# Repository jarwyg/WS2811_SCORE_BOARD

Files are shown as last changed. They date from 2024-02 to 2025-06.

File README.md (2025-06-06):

# WS2811_SCORE_BOARD

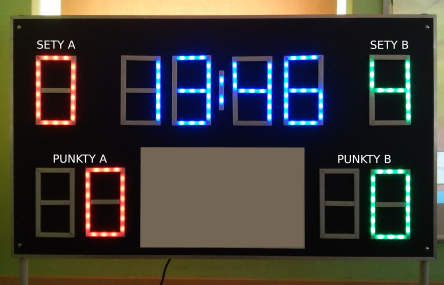
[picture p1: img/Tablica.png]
Tablica


W 2017 wraz z znajomym z roku stworzyliśmy tablicę wyników zbudowaną z wykorzystaniem pasków LED WS2811.

W 2024 projekt został ulepszony pod względem hardware oraz firmware. Aktualnie jest opublikownay jako open-source (MIT License) 

# Firmware

Firmware jest napisany w jęzku c.
Projekt był stworzony w Eclipse z AVR plugin (kompilator avr-gcc). Katalog Release zawiera pliki makefile więc można projekt skompliować z poziomu terminala.
Gotowe pliki binarne można znaleźć poniżej

[Firmware Release v1.2](https://github.com/jarwyg/WS2811_SCORE_BOARD/releases/tag/v1.2)

# Receiver

Odbiornik działa na mikrokontrolerze Atmega88/168/328 (16MHz - zawnętrzny oscylator).
Czas jest brany z RTC PCF8563.
Płytka powinna mieć wgrany bootloader z arduino UNO. Dzięki temu po podłączeniu przejściówki USB-UART łatwiej będzie wgrać aktualizację/zobaczyć debug podczas pracy układu. Tablica prawdopodobnie będzie w niedostępnym miejscu więc zalecam zostawienie długiego przewodu USB/RS232 

PCB
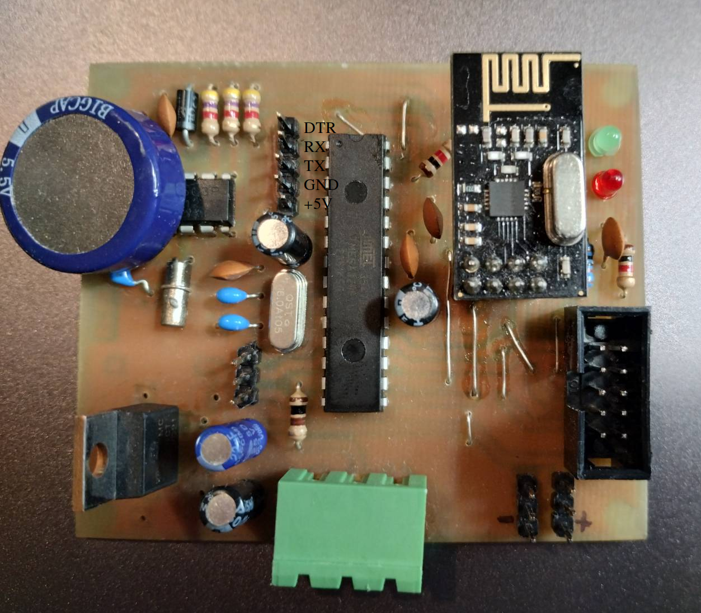
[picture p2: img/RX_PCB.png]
PCB_RX


# Transmitter

Pilot działa na mikrokontrolerze Atmega88/168/328 (8MHz - wewnętrzny oscylator)
Domyślnie jest w trybie uśpienia i pownien pobierać mniej niż 70uA.
Komunikacja z odbiornikiem odbywa się tylko w jedną stronę.

Opis przycisków
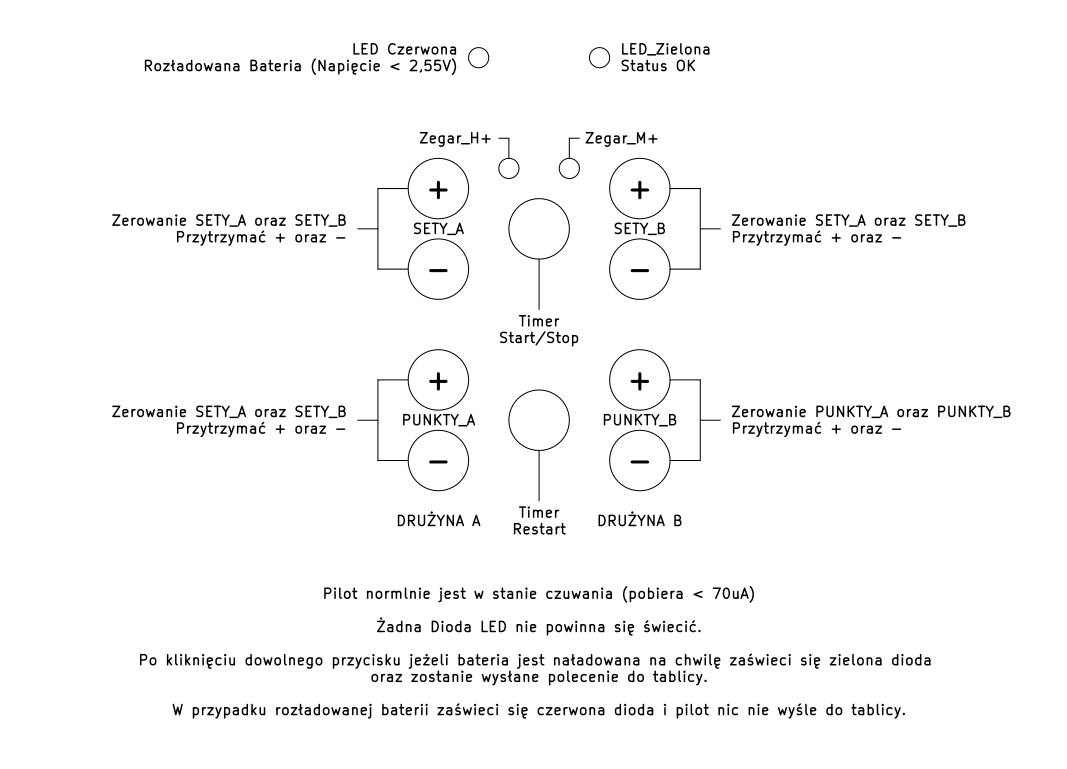
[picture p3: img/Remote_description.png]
Opis przycisków


PCB
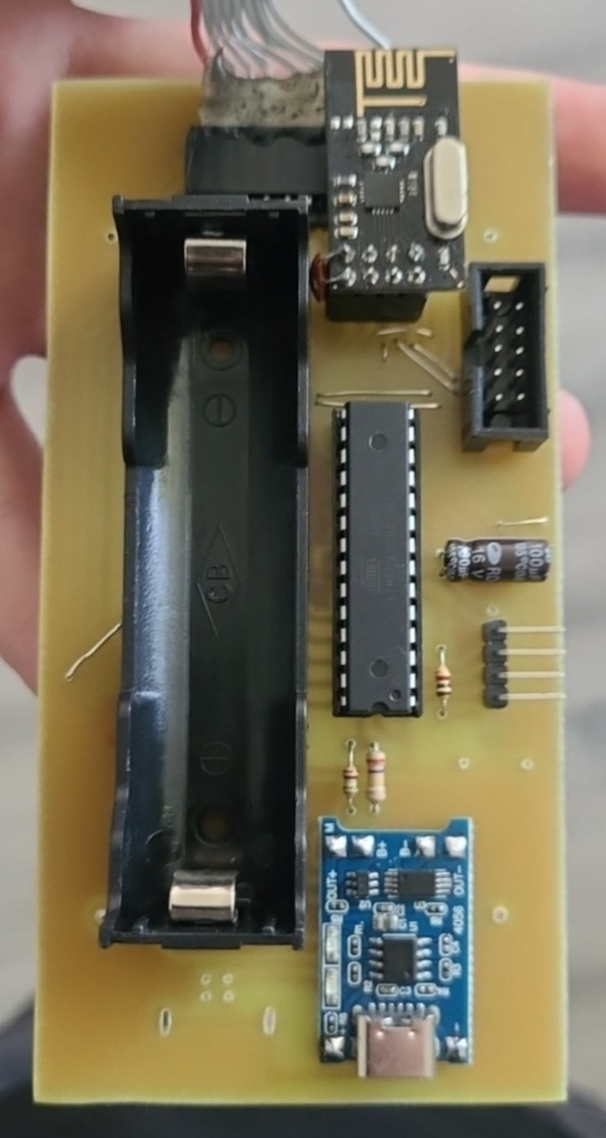
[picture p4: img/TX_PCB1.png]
PCB_TX1


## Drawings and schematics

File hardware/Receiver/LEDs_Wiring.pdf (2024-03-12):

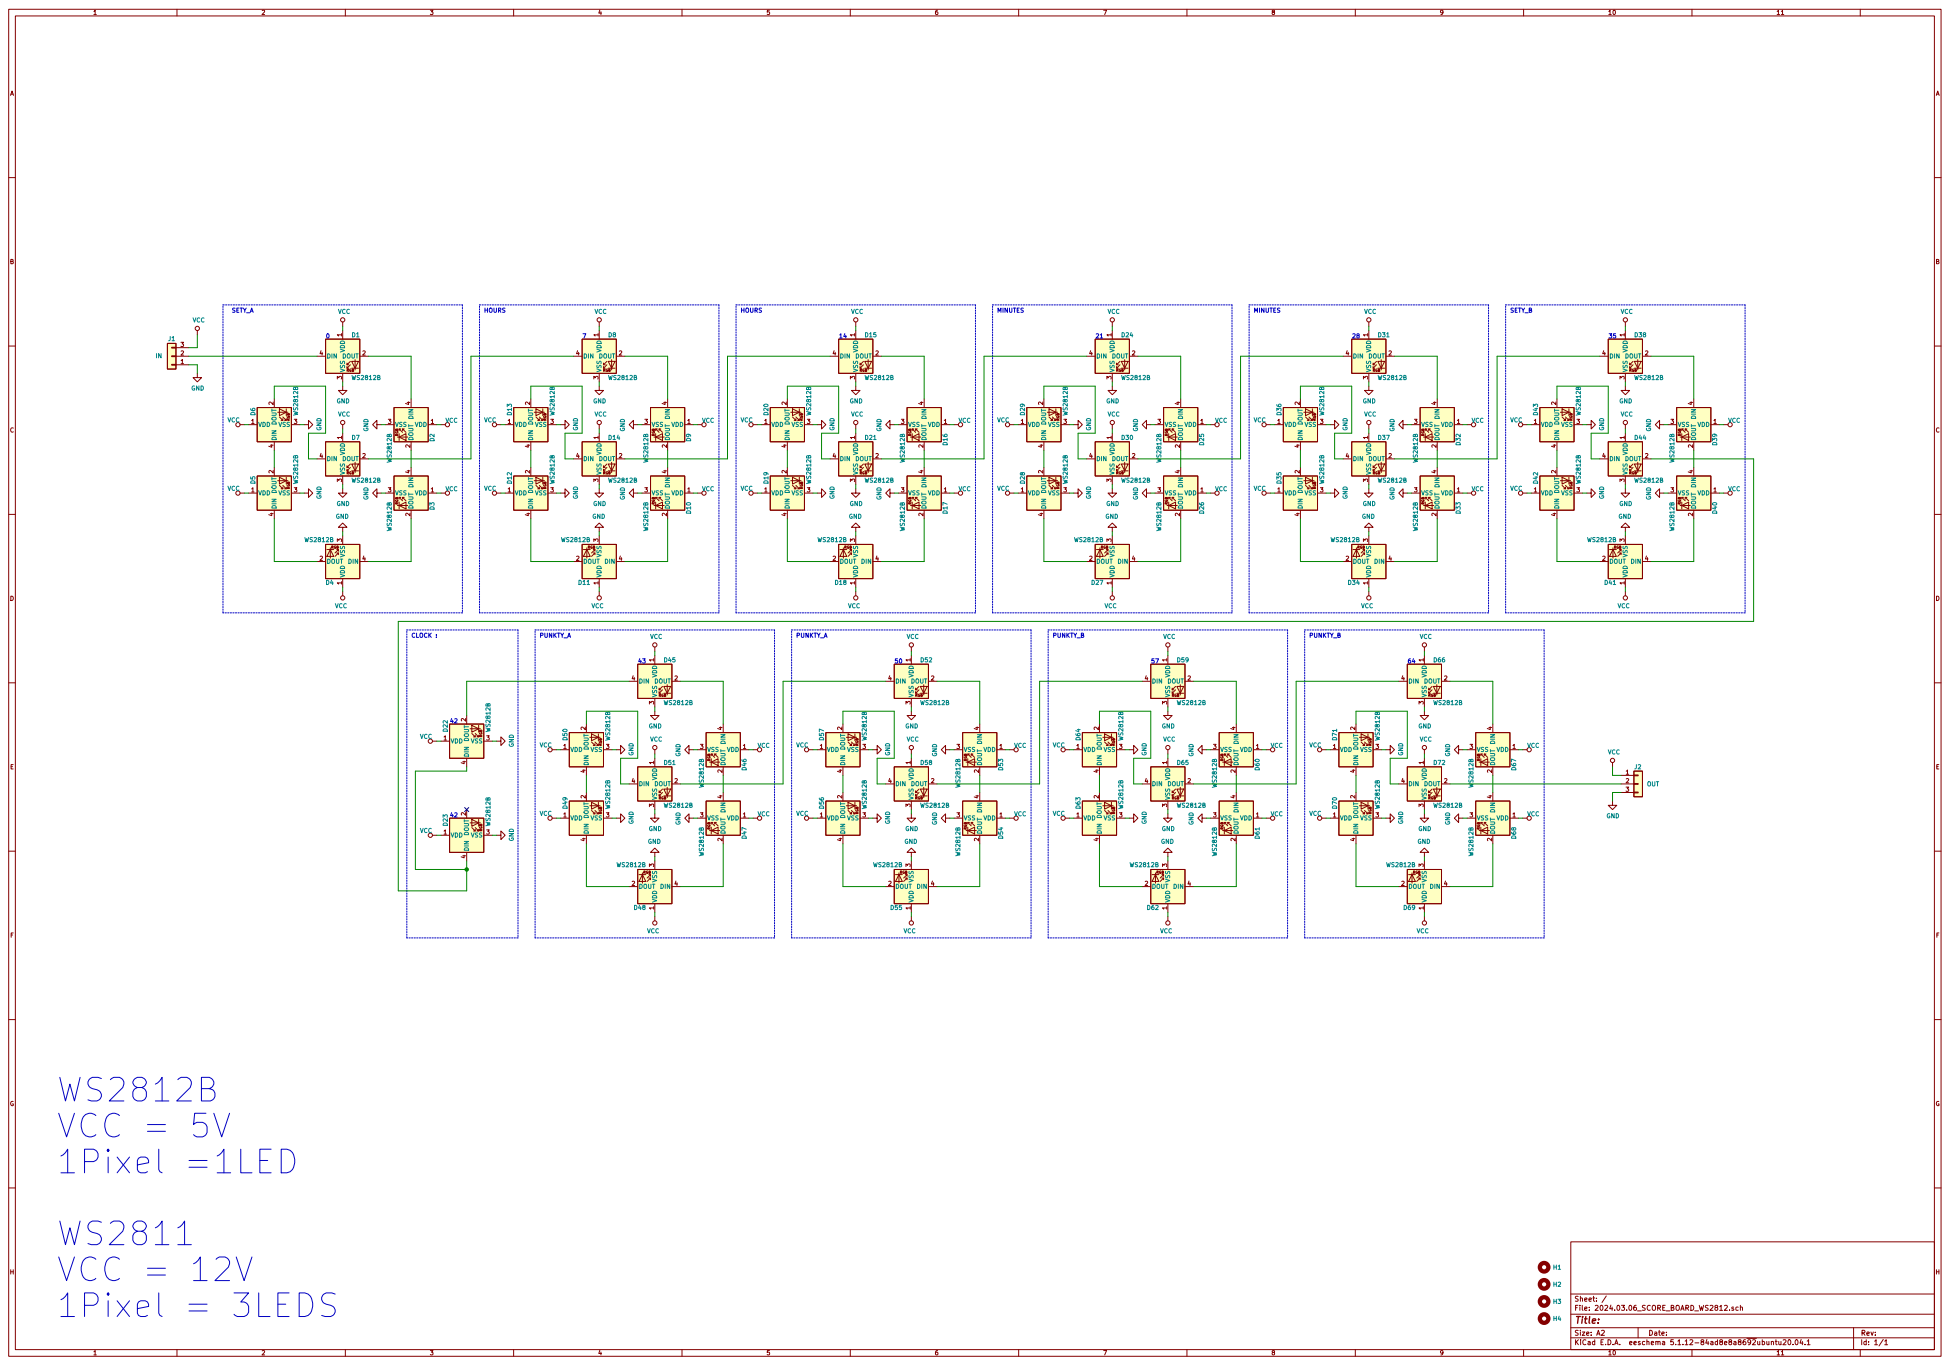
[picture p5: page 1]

3 DIN 4 D1WS2812B GND GND GND GND GND GND GND GND GND GND GND GND GND GND GND
RGB VDD

3 DIN 4 D15 WS2812B RGB VDD 1 DOUT

3 DIN 4 D30 WS2812B GND GND GND GNDRGB VDD
VCC

4 D28 WS2812B GND RGB VDD 1 DOUT

3 DIN 4 D11 WS2812B RGB VDD 1 DOUT

3 DIN 4 D18 WS2812B RGB VDD 1 DOUT

3 DIN 4 D27 WS2812B RGB VDD 1 DOUT

3 DIN 4 D52 WS2812B RGB VDD 1 DOUT

4 D53 WS2812B GND RGB VDD 1 DOUT

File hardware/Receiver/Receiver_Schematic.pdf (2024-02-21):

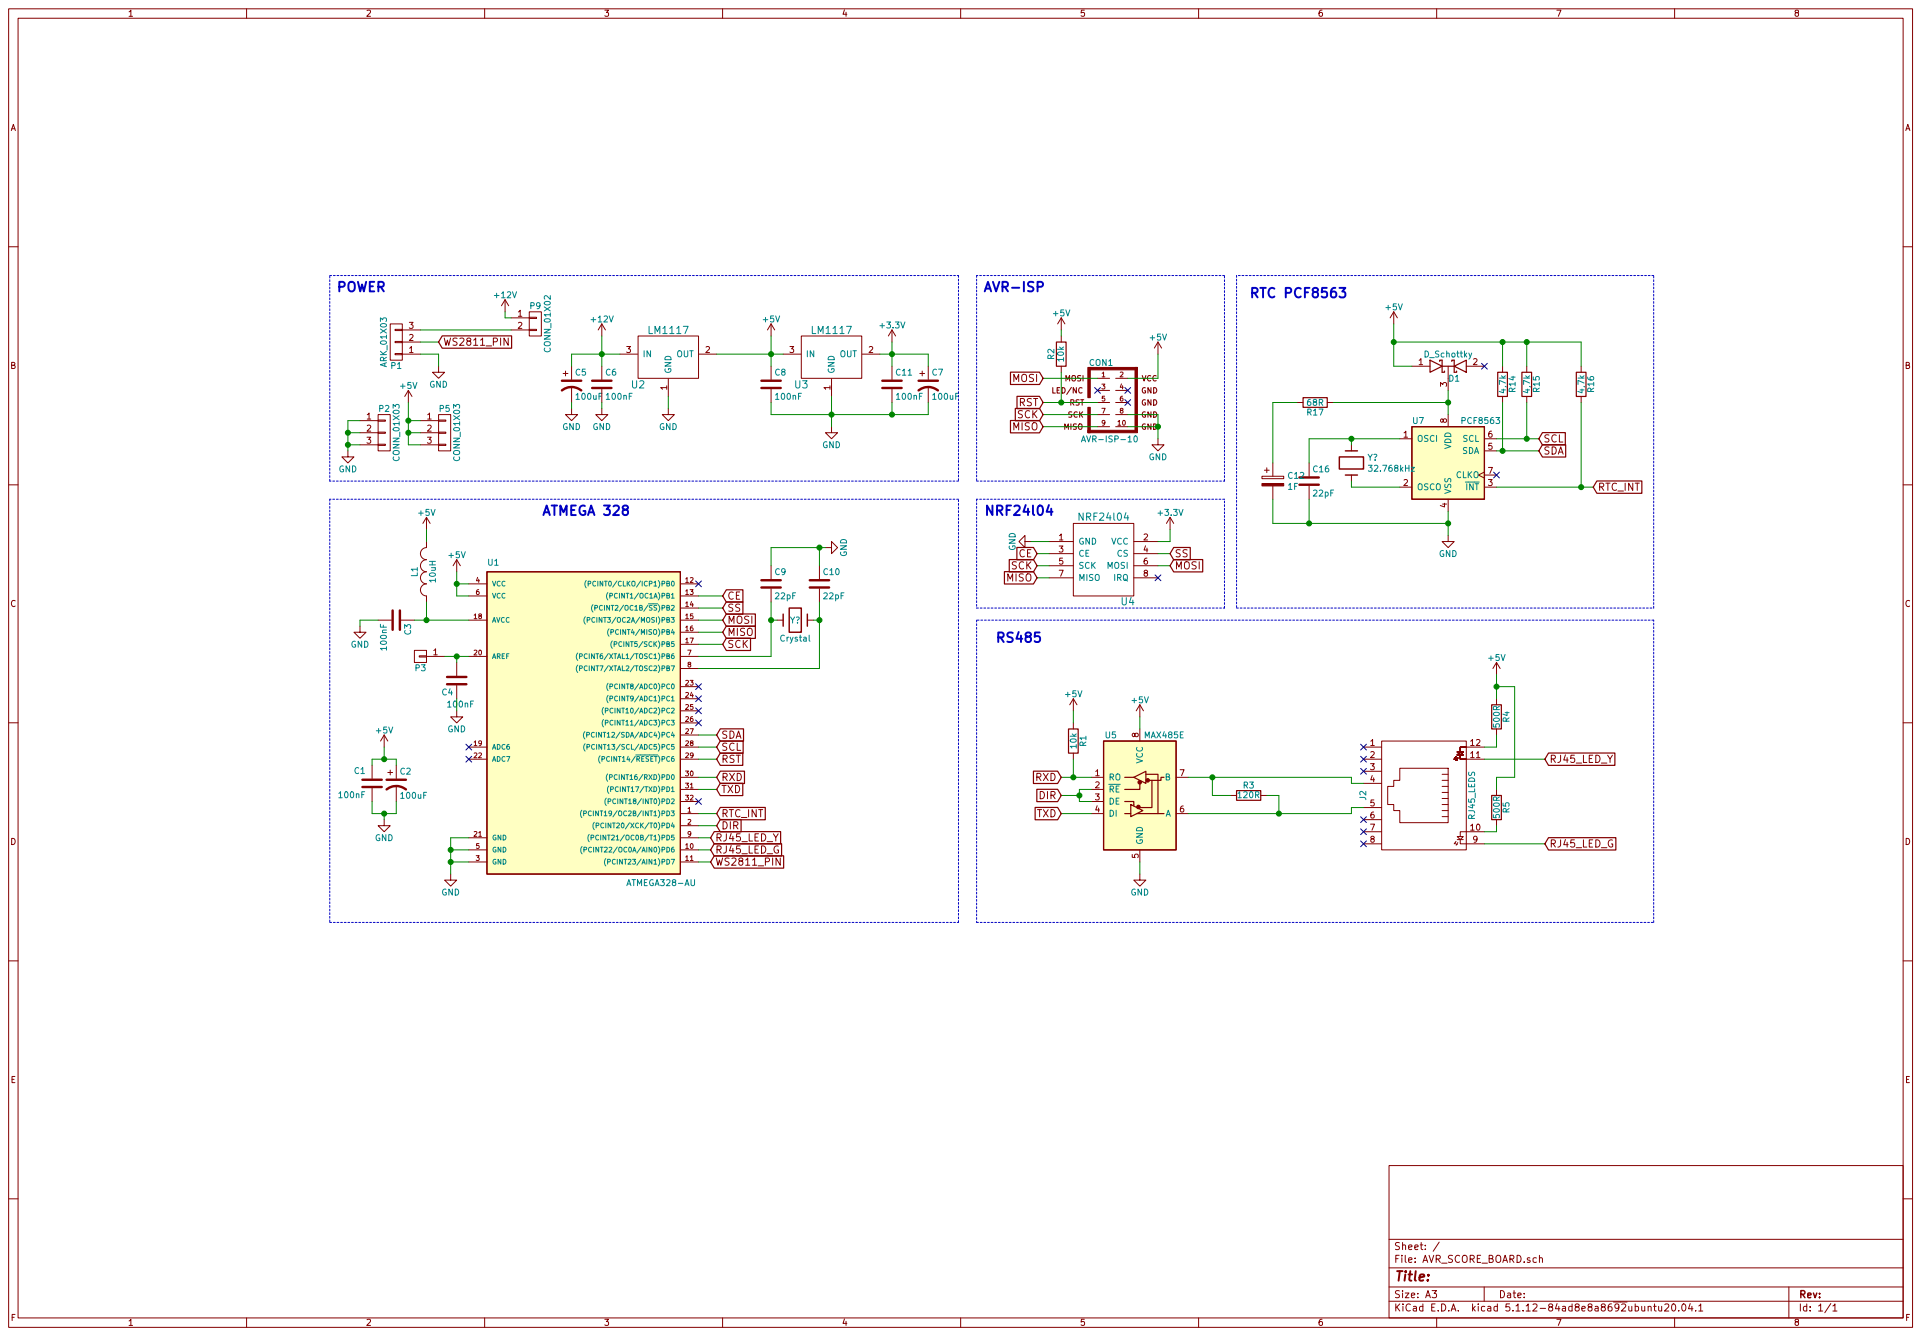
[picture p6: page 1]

9 CON1 AVR-ISP-10
VCC GND GND GND

4 SDA 5 SCL 6 CLKO 7 VDD

File: AVR_SCORE_BOARD.sch Sheet: / GND

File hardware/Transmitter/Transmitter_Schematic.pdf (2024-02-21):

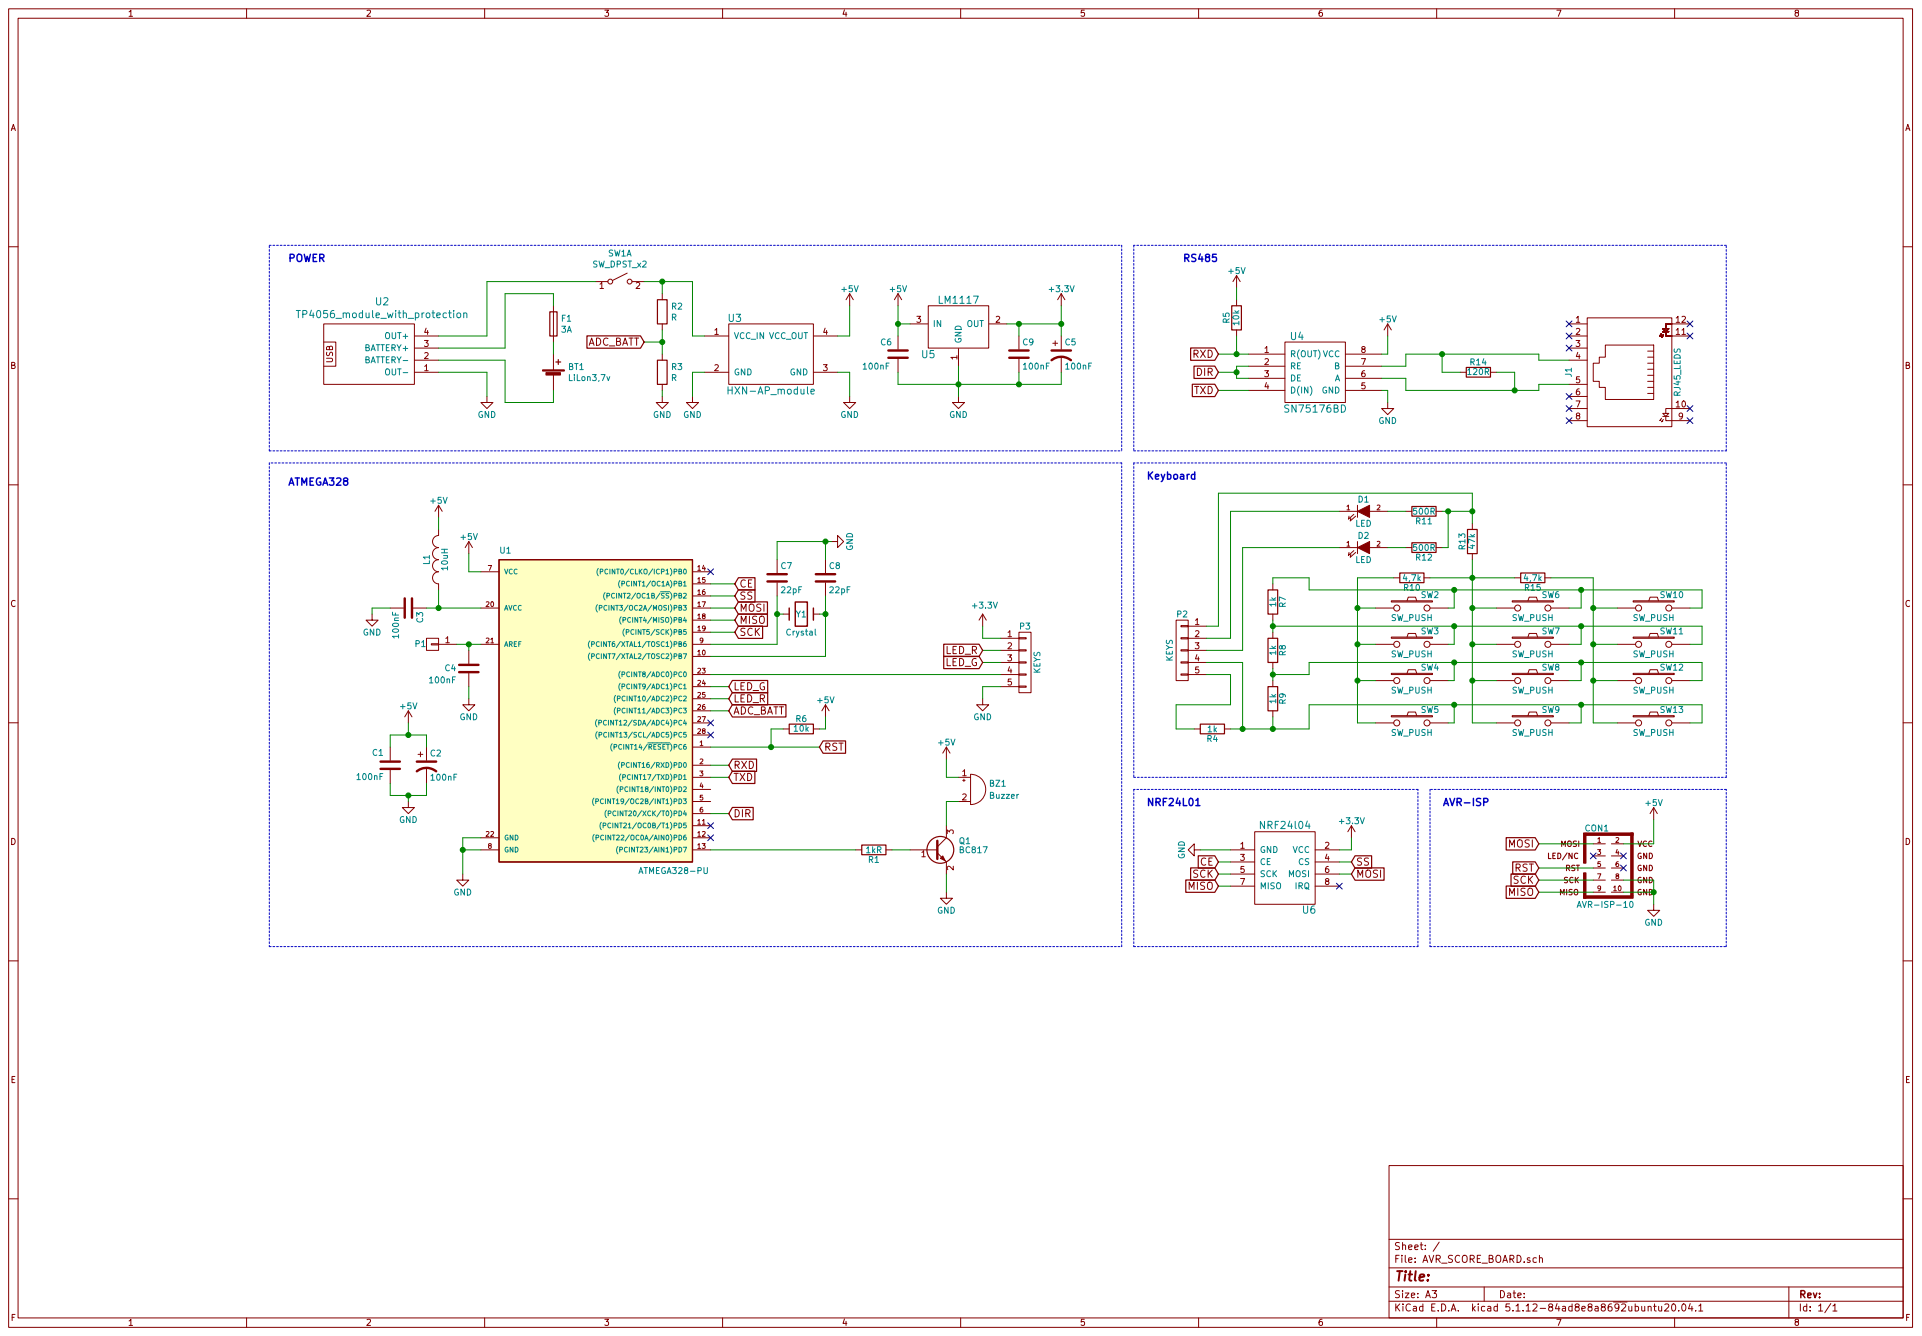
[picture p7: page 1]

VCC GND GND GND

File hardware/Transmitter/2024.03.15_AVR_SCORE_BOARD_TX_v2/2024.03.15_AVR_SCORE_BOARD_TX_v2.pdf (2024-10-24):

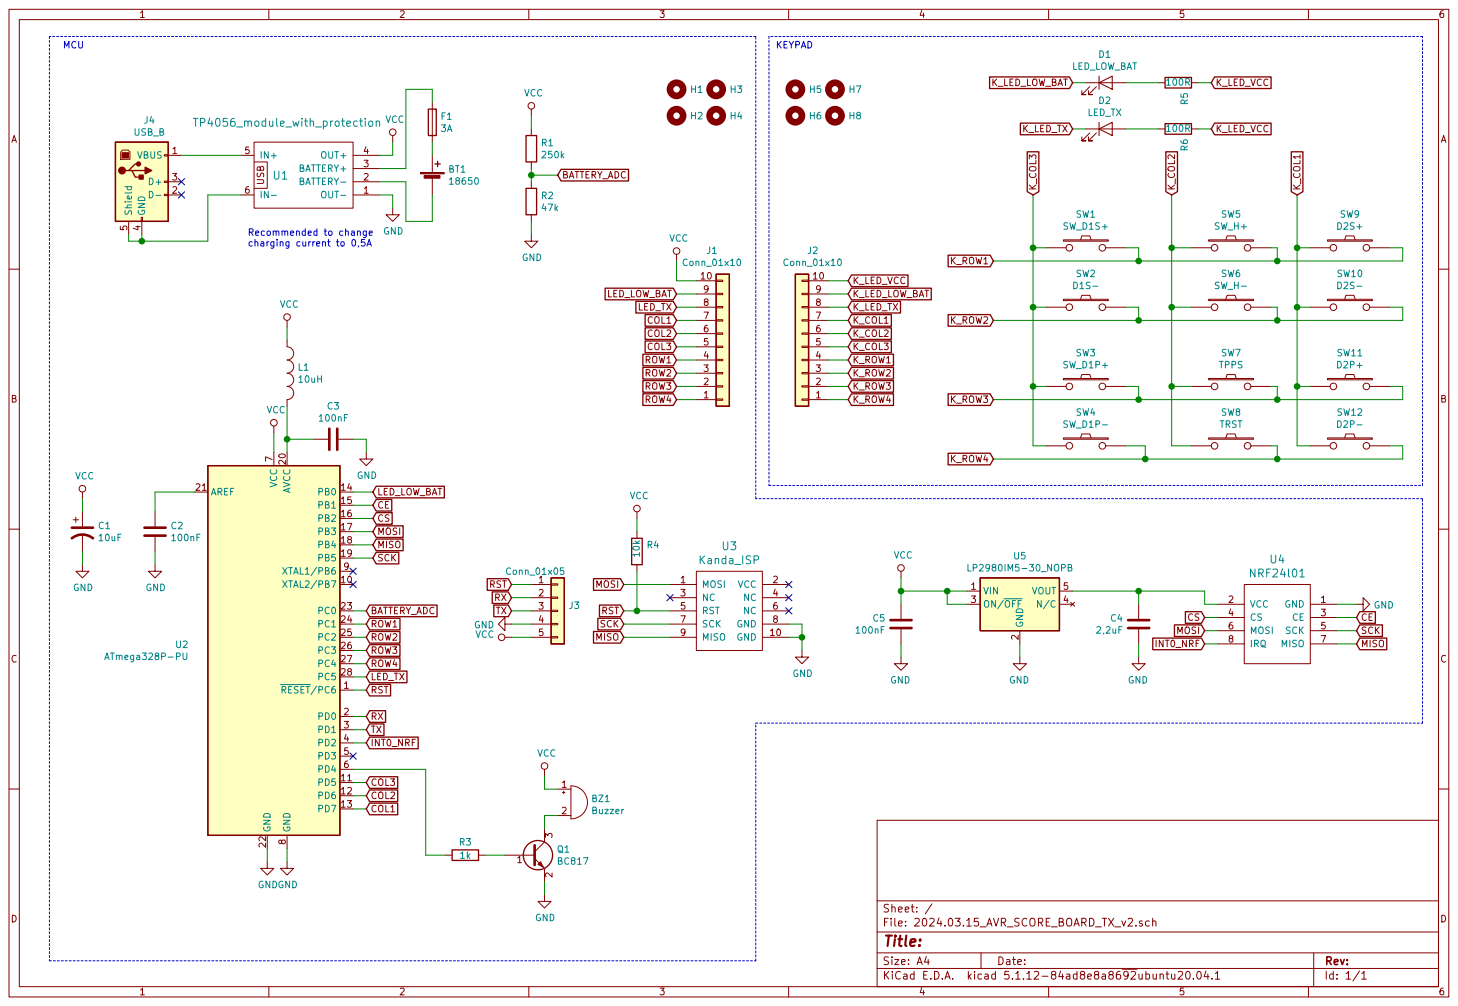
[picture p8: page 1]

8 XTAL1/PB6 9 U2 ATmega328P-PU MOSI 1 GND 10 VCC 2 NC 3 NC 4 RST 5 NC 6 SCK 7 GND 8 MISO 9 U3 Kanda_ISP

INT0_NRF RST MOSI SCK MISO

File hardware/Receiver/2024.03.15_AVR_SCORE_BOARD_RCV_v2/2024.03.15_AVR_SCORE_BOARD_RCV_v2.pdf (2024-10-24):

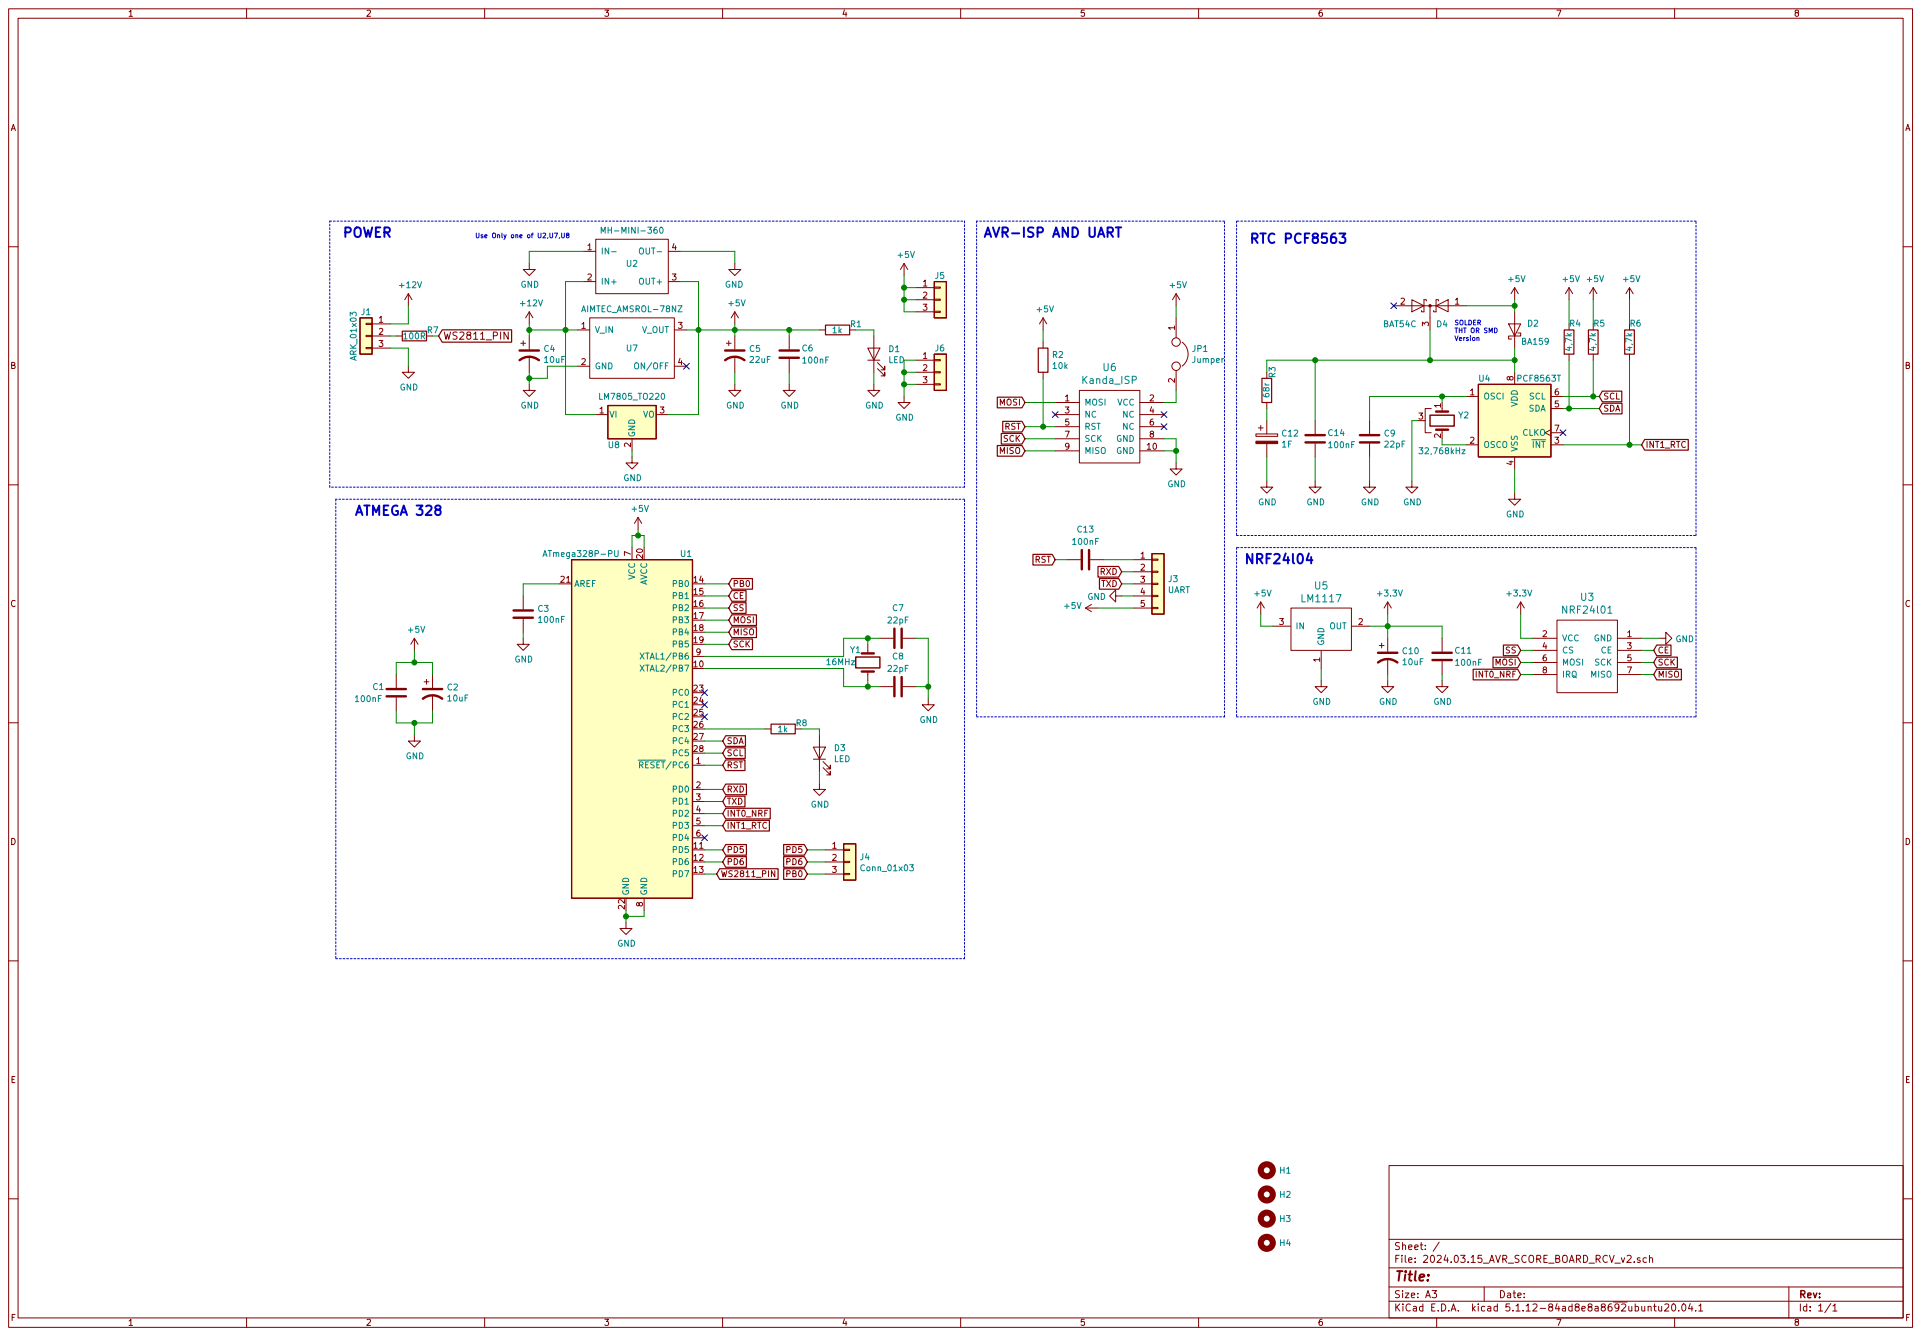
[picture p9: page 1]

4 SDA 5 SCL 6 CLKO 7 VDD

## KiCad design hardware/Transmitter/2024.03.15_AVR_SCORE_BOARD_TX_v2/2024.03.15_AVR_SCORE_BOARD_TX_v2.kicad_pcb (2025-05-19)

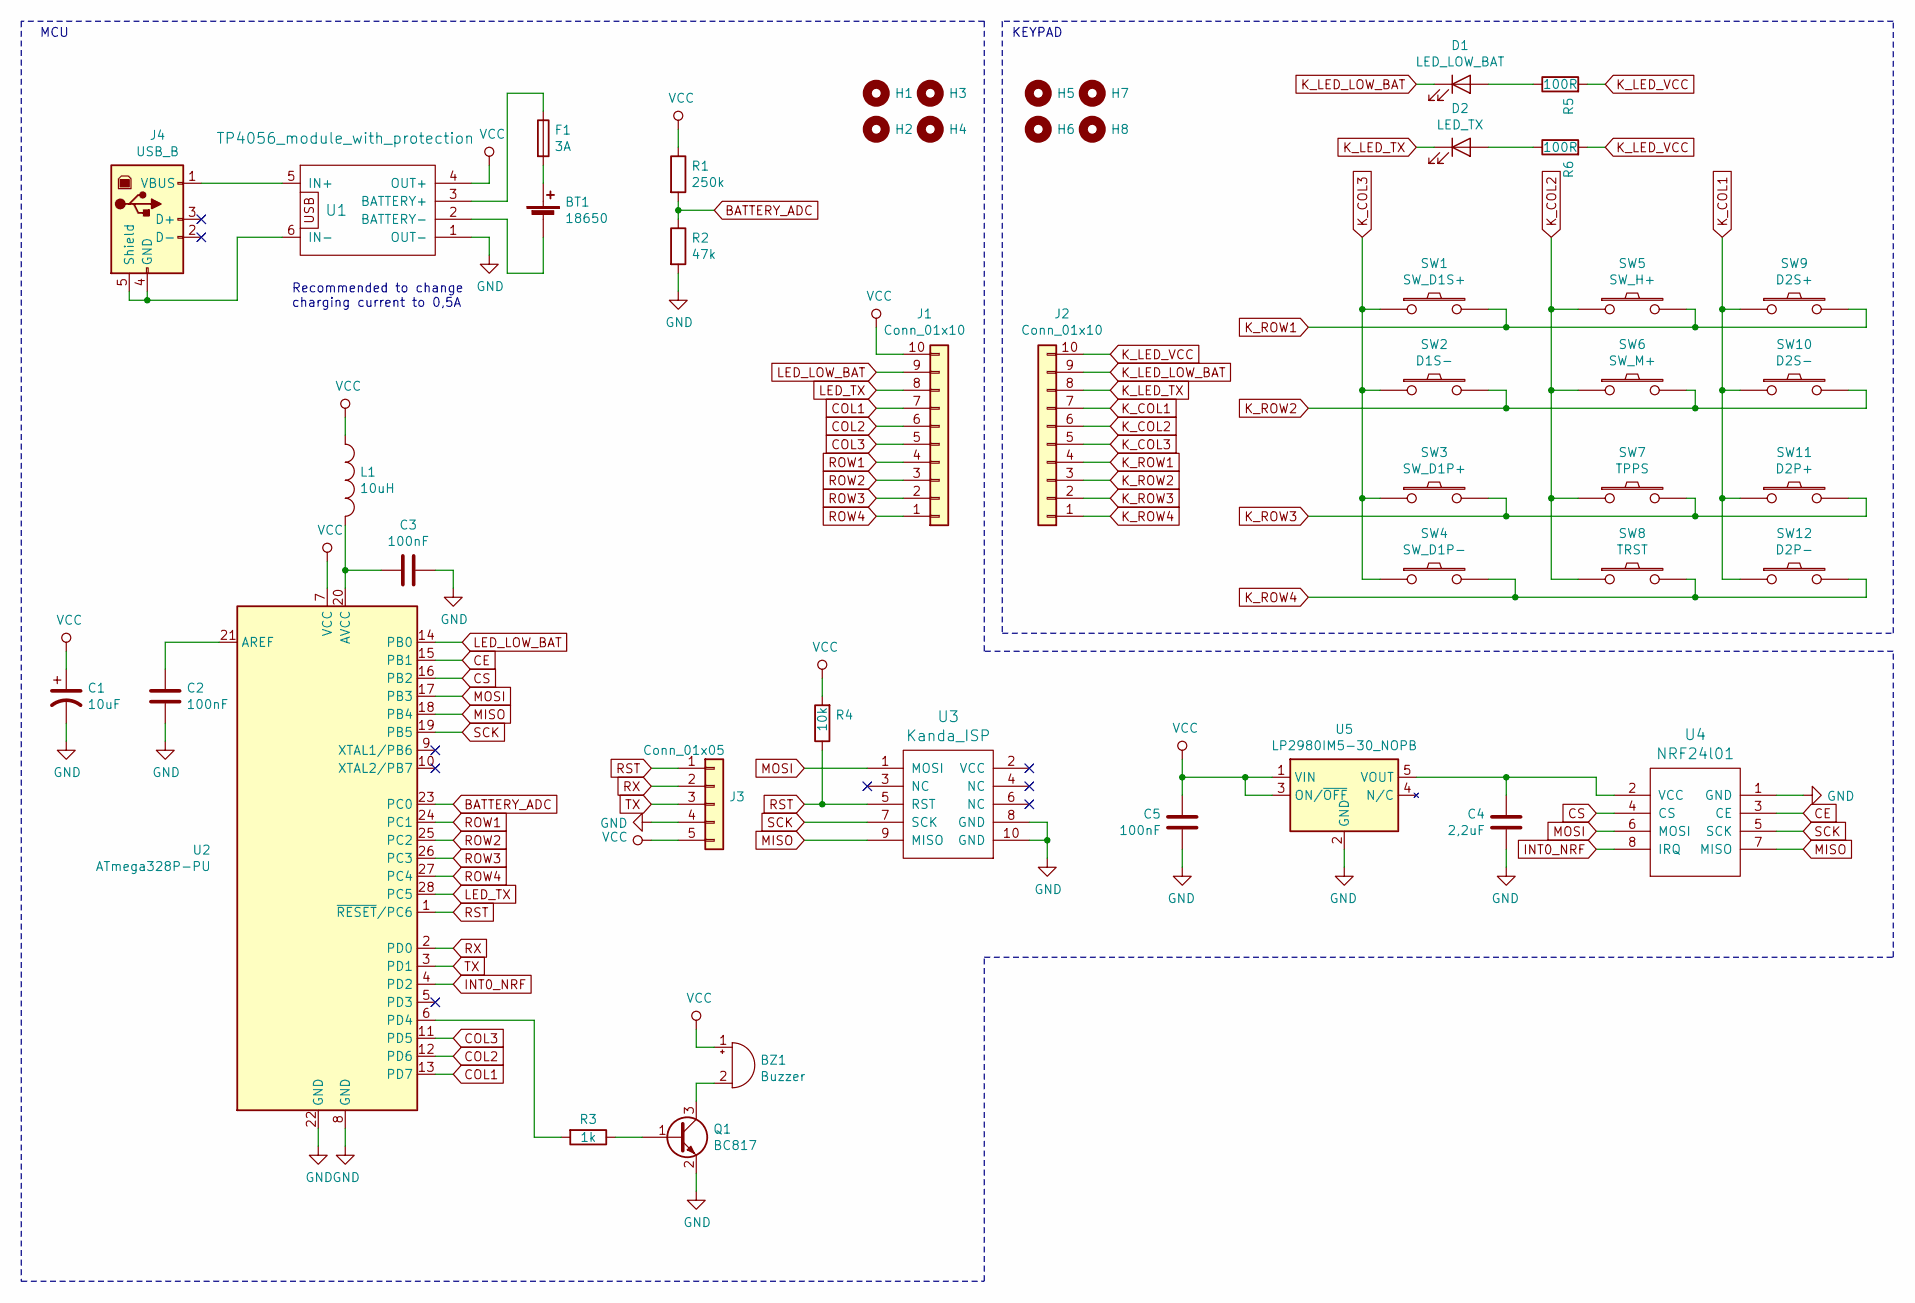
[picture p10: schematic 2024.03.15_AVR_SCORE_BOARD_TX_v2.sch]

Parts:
BT1: 18650; BatteryHolder_MPD_BH-18650-PC2
BZ1: Buzzer; BUZZER(7,5mm)
C1: 10uF; C(2,5mm)
C2, C3, C5: 100nF; C_0805_2012Metric_Pad1.15x1.40mm_HandSolder
C4: 2,2uF; C_0805_2012Metric_Pad1.15x1.40mm_HandSolder
D1: LED_LOW_BAT; LED_D3.0mm
D2: LED_TX; LED_D3.0mm
F1: 3A; Fuse_0805_2012Metric_Pad1.15x1.40mm_HandSolder
H1, H2, H3, H4, H5, H6, H7, H8: MountingHole; MountingHole_3mm
J1, J2: Conn_01x10; conn_10
J3: Conn_01x05; conn_5
J4: USB_B
L1: 10uH; L_0805_2012Metric_Pad1.15x1.40mm_HandSolder
Q1: BC817; SOT-23
R1: 250k; R_MY_DIN0204_L3.6mm_D1.6mm_P7.62mm
R2: 47k; R_MY_DIN0204_L3.6mm_D1.6mm_P7.62mm
R3: 1k; R_MY_DIN0204_L3.6mm_D1.6mm_P7.62mm
R4: 10k; R_0805_2012Metric_Pad1.15x1.40mm_HandSolder
R5, R6: 100R; C_0805_2012Metric_Pad1.15x1.40mm_HandSolder
SW1: SW_D1S+; SW_SMALL(12X12)
SW2: D1S-; SW_SMALL(12X12)
SW3: SW_D1P+; SW_SMALL(12X12)
SW4: SW_D1P-; SW_SMALL(12X12)
SW5: SW_H+; SW_SMALL(6X6)
SW6: SW_M+; SW_SMALL(6X6)
SW7: TPPS; SW_SMALL(12X12)
SW8: TRST; SW_SMALL(12X12)
SW9: D2S+; SW_SMALL(12X12)
SW10: D2S-; SW_SMALL(12X12)
SW11: D2P+; SW_SMALL(12X12)
SW12: D2P-; SW_SMALL(12X12)
U1: TP4056_module_with_protection; TP4056-18650
U2: ATmega328P-PU; DIP-28_W7.62mm
U3: Kanda_ISP; KANDA_ISP
U4: NRF24l01
U5: LP2980IM5-30_NOPB; SOT-23-5

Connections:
BATTERY_ADC: R1.2, R2.1, U2.23 (PC0)
CE: U2.15 (PB1), U4.3 (CE)
COL1: J1.7, U2.13 (PD7)
COL2: J1.6, U2.12 (PD6)
COL3: J1.5, U2.11 (PD5)
CS: U2.16 (PB2), U4.4 (CS)
GND: C1.2, C2.2, C3.1, C4.2, C5.2, J3.4, Q1.2 (E), R2.2, U1.1 (OUT-), U2.8 (GND), U2.22 (GND), U3.8 (GND), U3.10 (GND), U4.1 (GND), U5.2 (GND)
INT0_NRF: U2.4 (PD2), U4.8 (IRQ)
K_COL1: J2.7, SW9.1, SW10.1, SW11.1, SW12.1
K_COL2: J2.6, SW5.1, SW6.1, SW7.1, SW8.1
K_COL3: J2.5, SW1.1, SW2.1, SW3.1, SW4.1
K_LED_LOW_BAT: D1.1 (K), J2.9
K_LED_TX: D2.1 (K), J2.8
K_LED_VCC: J2.10, R5.2, R6.2
K_ROW1: J2.4, SW1.2, SW5.2, SW9.2
K_ROW2: J2.3, SW2.2, SW6.2, SW10.2
K_ROW3: J2.2, SW3.2, SW7.2, SW11.2
K_ROW4: J2.1, SW4.2, SW8.2, SW12.2
LED_LOW_BAT: J1.9, U2.14 (PB0)
LED_TX: J1.8, U2.28 (PC5)
MISO: U2.18 (PB4), U3.9 (MISO), U4.7 (MISO)
MOSI: U2.17 (PB3), U3.1 (MOSI), U4.6 (MOSI)
unnamed: BT1.1 (+), F1.2
unnamed: BT1.2 (-), U1.2 (BATTERY-)
unnamed: BZ1.2 (+), Q1.3 (C)
unnamed: C2.1, U2.21 (AREF)
unnamed: C3.2, L1.2, U2.20 (AVCC)
unnamed: C4.1, U4.2 (VCC), U5.5 (VOUT)
unnamed: D1.2 (A), R5.1
unnamed: D2.2 (A), R6.1
unnamed: F1.1, U1.3 (BATTERY+)
unnamed: J4.1 (VBUS), U1.5 (IN+)
unnamed: J4.4 (GND), J4.5 (Shield), U1.6 (IN-)
unnamed: Q1.1 (B), R3.1
unnamed: R3.2, U2.6 (PD4)
ROW1: J1.4, U2.24 (PC1)
ROW2: J1.3, U2.25 (PC2)
ROW3: J1.2, U2.26 (PC3)
ROW4: J1.1, U2.27 (PC4)
RST: J3.1, R4.1, U2.1 (~RESET~/PC6), U3.5 (RST)
RX: J3.2, U2.2 (PD0)
SCK: U2.19 (PB5), U3.7 (SCK), U4.5 (SCK)
TX: J3.3, U2.3 (PD1)
VCC: BZ1.1 (-), C1.1, C5.1, J1.10, J3.5, L1.1, R1.1, R4.2, U1.4 (OUT+), U2.7 (VCC), U5.1 (VIN), U5.3 (ON/~OFF)

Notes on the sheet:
Recommended to change charging current to 0,5A
KEYPAD
MCU

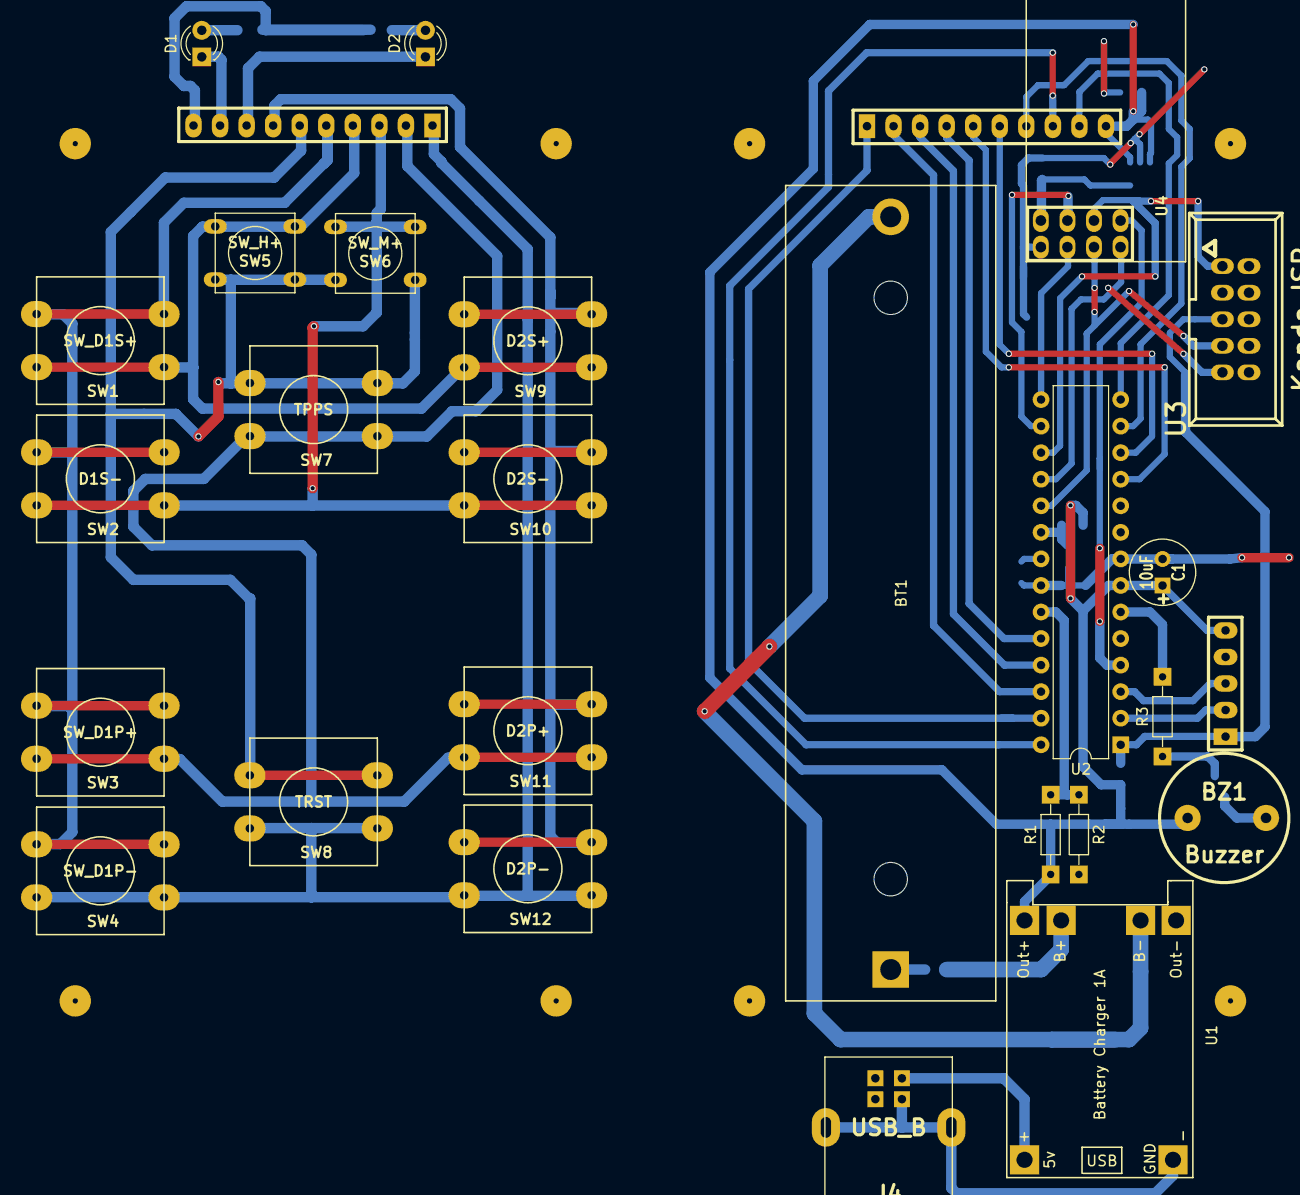
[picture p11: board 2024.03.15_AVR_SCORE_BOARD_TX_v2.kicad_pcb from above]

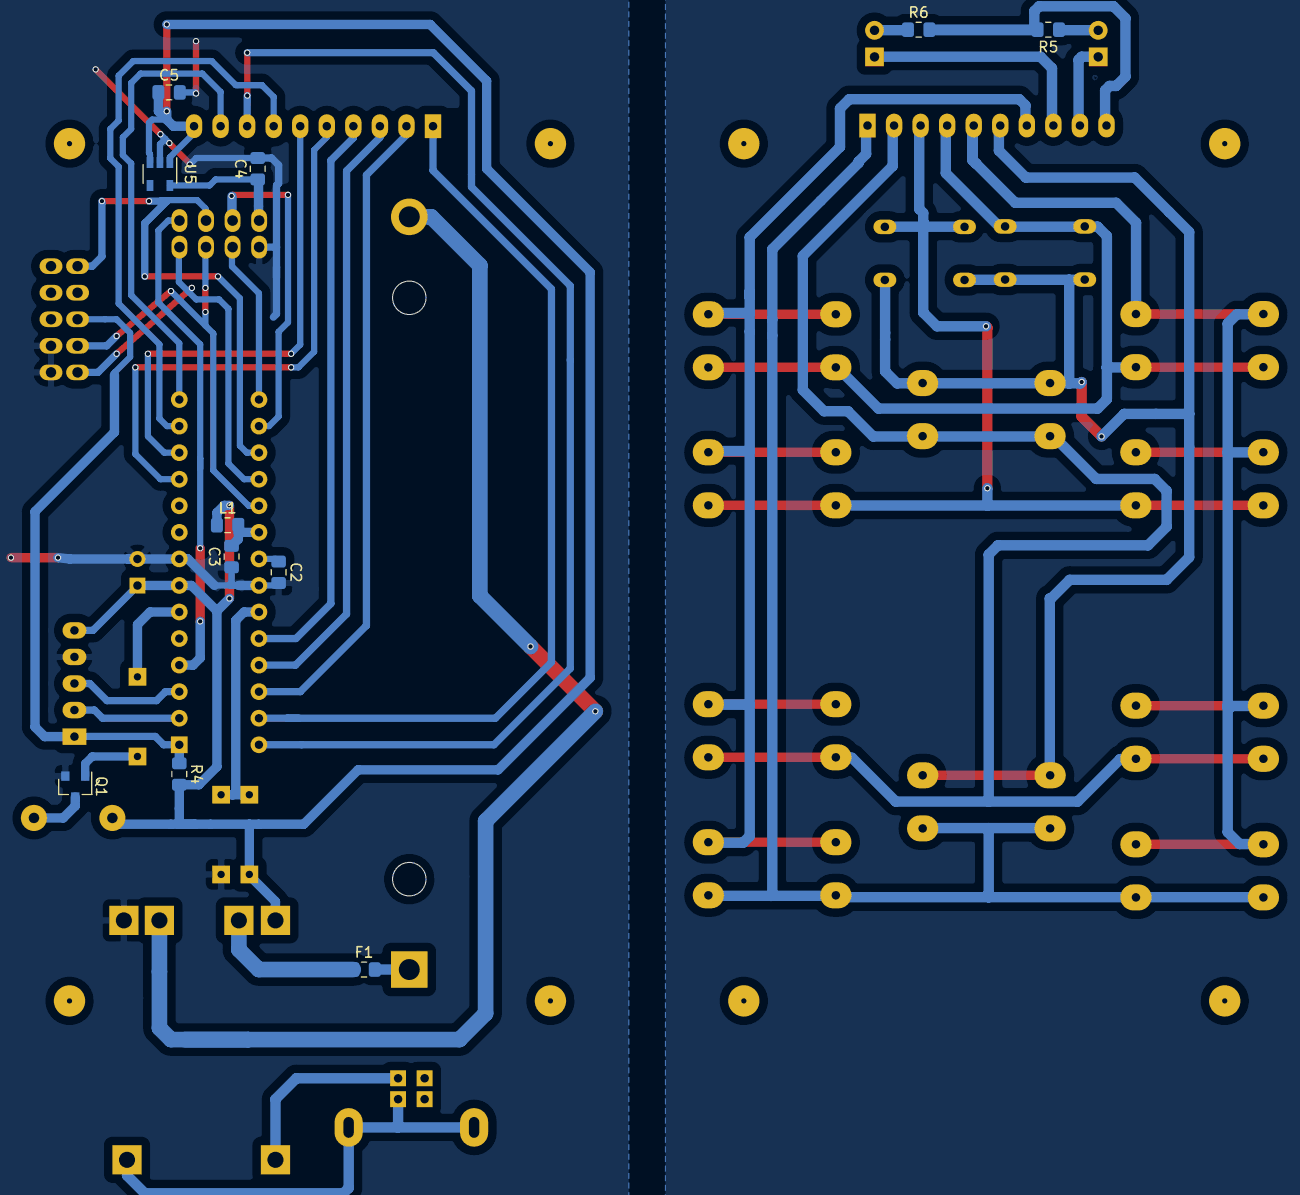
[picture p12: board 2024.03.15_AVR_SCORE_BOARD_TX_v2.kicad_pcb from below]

Board: 2 copper layers, 47 parts (11 on the bottom side), 44 nets.

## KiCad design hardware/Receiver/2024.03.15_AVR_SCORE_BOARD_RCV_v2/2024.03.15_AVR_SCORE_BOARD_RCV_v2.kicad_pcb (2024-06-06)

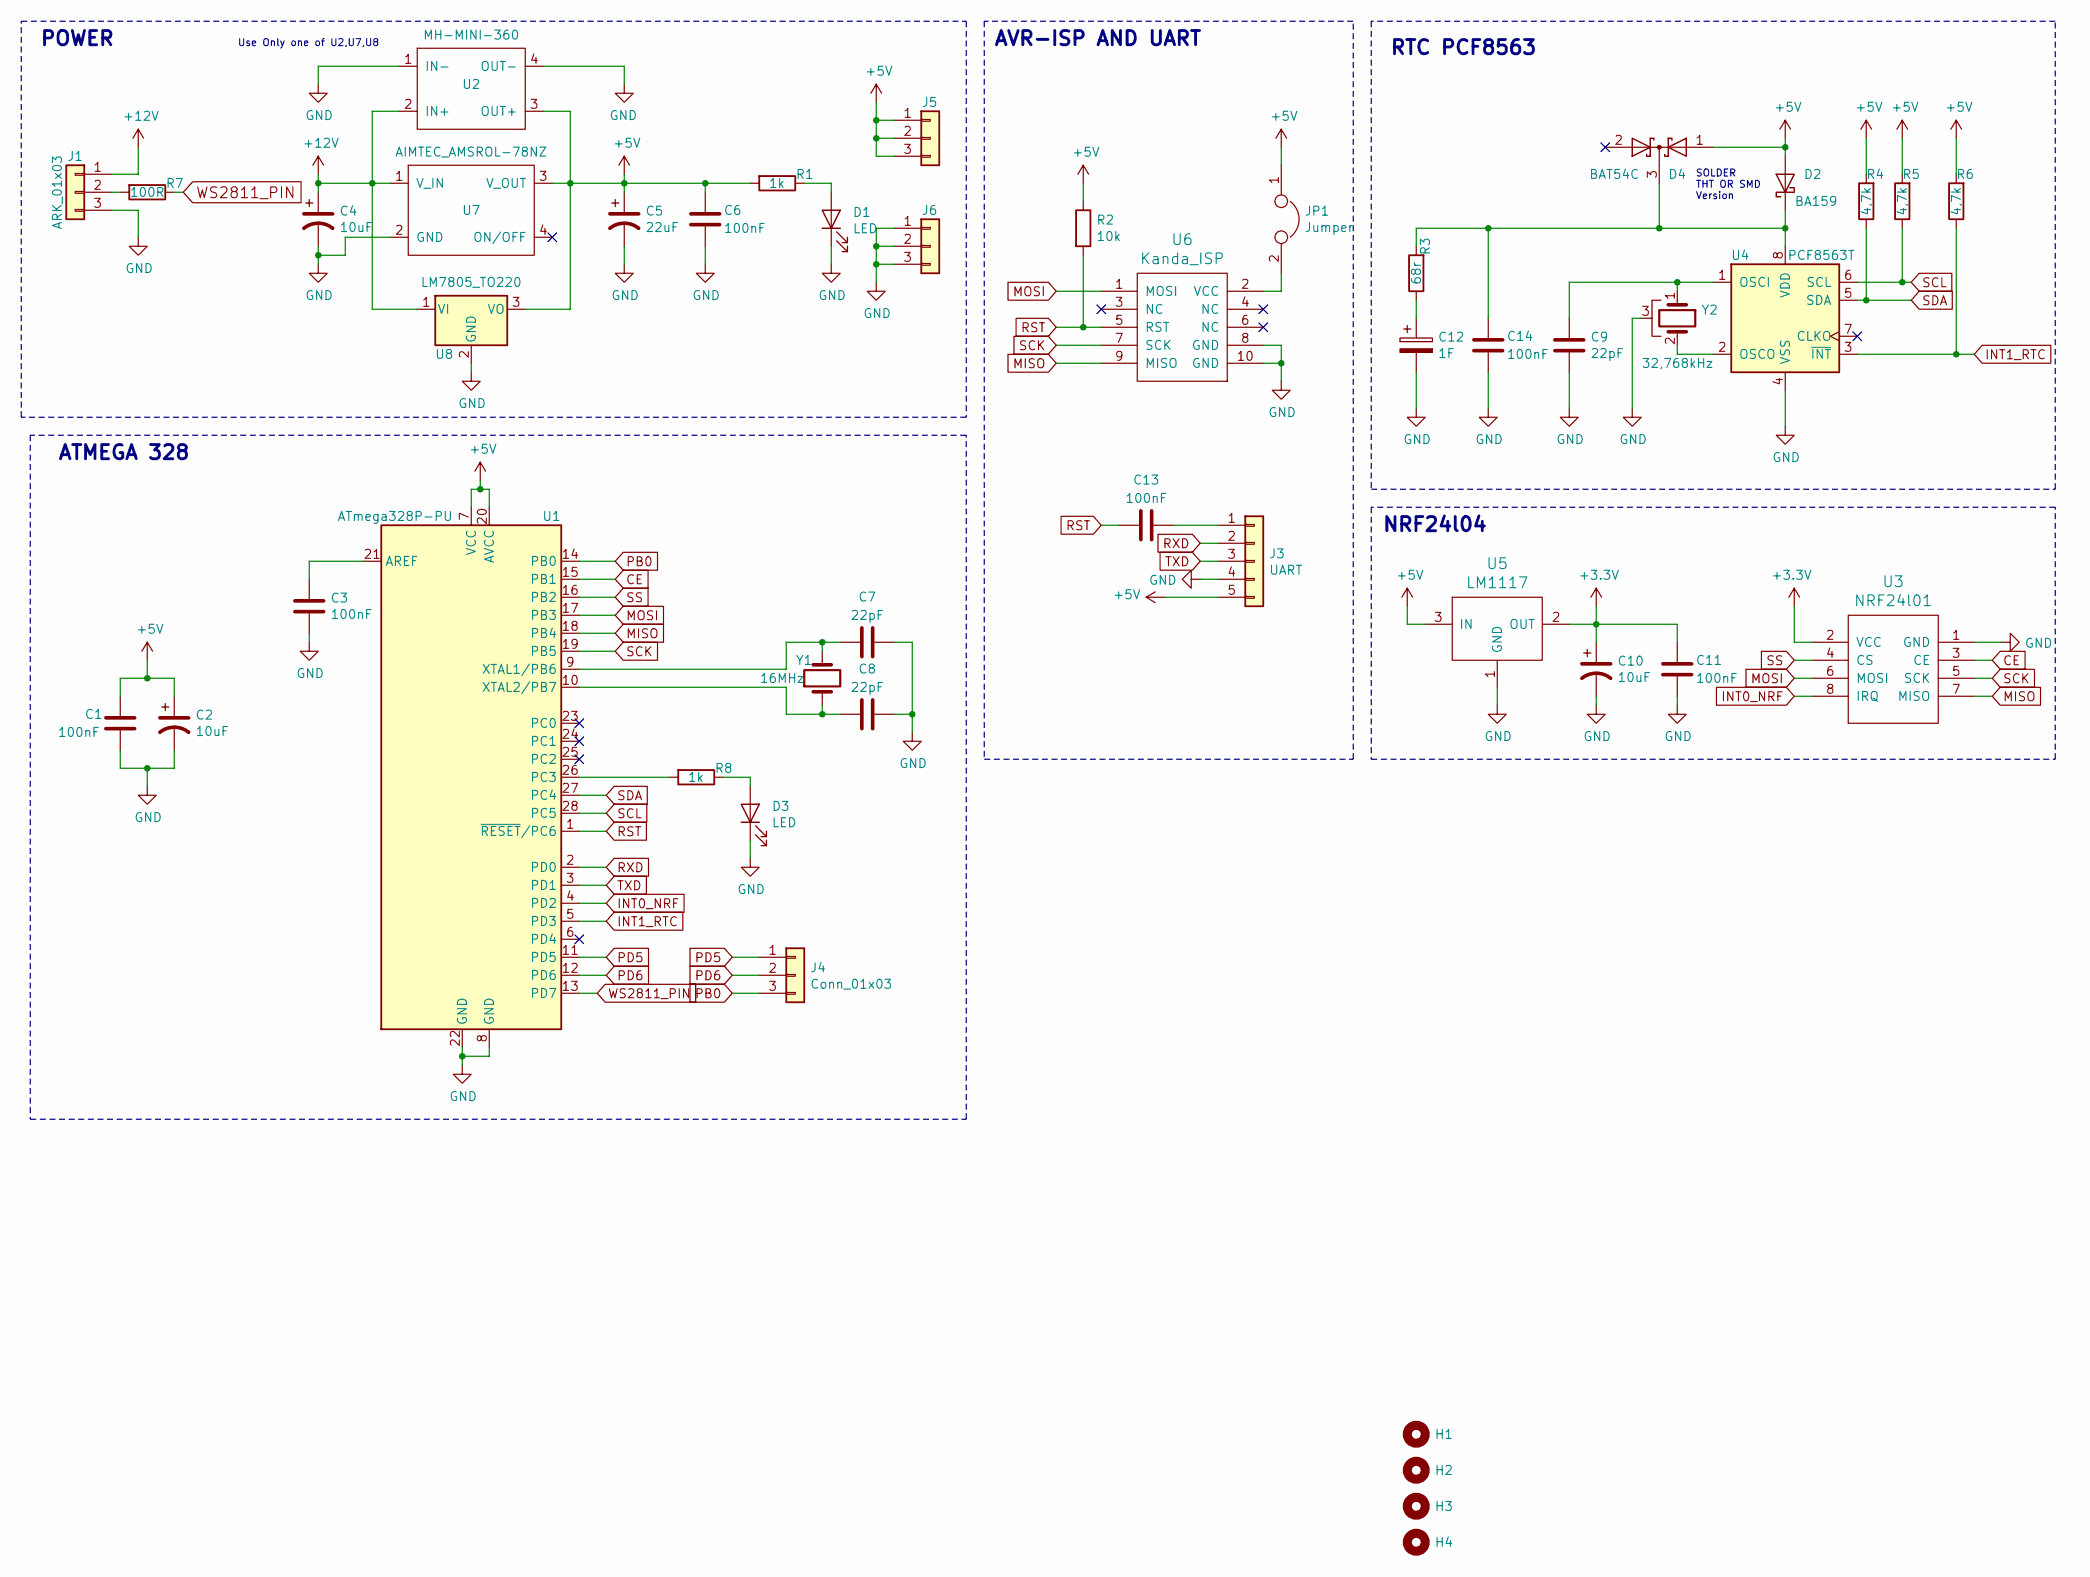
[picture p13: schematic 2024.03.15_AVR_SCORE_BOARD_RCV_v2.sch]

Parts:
C1, C3, C6, C11, C14: 100nF; C[5,5mm]
C2, C4, C10: 10uF; C(2,5mm)
C5: 22uF; C(2,5mm)
C7, C8, C9: 22pF; C[5,5mm]
C12: 1F; C(3,5mm)
C13: 100nF; C_0805_2012Metric_Pad1.15x1.40mm_HandSolder
D1, D3: LED; LED_D3.0mm
D2: BA159; D_A-405_P7.62mm_Horizontal
D4: BAT54C; SOT-23
H1, H2, H3, H4: MountingHole; MountingHole_3.2mm_M3
J1: ARK_01x03; ARK_3PIN
J3: UART; conn_5
J4, J5, J6: Conn_01x03; conn_3
JP1: Jumper; SolderJumper-2_P1.3mm_Open_Pad1.0x1.5mm
R1, R8: 1k; R_MY_DIN0204_L3.6mm_D1.6mm_P7.62mm
R2: 10k; R_MY_DIN0204_L3.6mm_D1.6mm_P7.62mm
R3: 68r; R_MY_DIN0204_L3.6mm_D1.6mm_P7.62mm
R4, R5, R6: 4,7k; R_MY_DIN0204_L3.6mm_D1.6mm_P7.62mm
R7: 100R; R_MY_DIN0204_L3.6mm_D1.6mm_P7.62mm
U1: ATmega328P-PU; DIP-28_W7.62mm_LongPads
U2: MH-MINI-360; MH-MINI_DC_DC
U3: NRF24l01
U4: PCF8563T; DIP-8_W7.62mm_LongPads
U5: LM1117; TO263_MY
U6: Kanda_ISP
U7: AIMTEC_AMSROL-78NZ; AMSROL-78NZ
U8: LM7805_TO220; TO-220-3_Vertical
Y1: 16MHz; Crystal_HC49-U_Vertical
Y2: 32,768kHz; Crystal_DS10_D1.0mm_L4.3mm_Horizontal_1EP_style2

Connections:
+3V3: C10.1, C11.1, U3.2 (VCC), U5.2 (OUT)
+5V: C1.1, C2.1, C5.1, C6.1, D2.2 (A), D4.1 (A), J3.5, J5.1, J5.2, J5.3, JP1.1, R1.2, R2.1, R4.2, R5.2, R6.2, U1.7 (VCC), U1.20 (AVCC), U2.3 (OUT+), U5.3 (IN), U7.3 (V_OUT), U8.3 (VO)
+12V: C4.1, J1.1, U2.2 (IN+), U7.1 (V_IN), U8.1 (VI)
CE: U1.15 (PB1), U3.3 (CE)
GND: C1.2, C2.2, C3.2, C4.2, C5.2, C6.2, C7.1, C8.1, C9.2, C10.2, C11.2, C12.2, C14.2, D1.1 (K), D3.1 (K), J1.3, J3.4, J6.1, J6.2, J6.3, U1.8 (GND), U1.22 (GND), U2.1 (IN-), U2.4 (OUT-), U3.1 (GND), U4.4 (VSS), U5.1 (GND), U6.8 (GND), U6.10 (GND), U7.2 (GND), U8.2 (GND), Y2.3
INT0_NRF: U1.4 (PD2), U3.8 (IRQ)
INT1_RTC: R6.1, U1.5 (PD3), U4.3 (~INT~)
MISO: U1.18 (PB4), U3.7 (MISO), U6.9 (MISO)
MOSI: U1.17 (PB3), U3.6 (MOSI), U6.1 (MOSI)
unnamed: C3.1, U1.21 (AREF)
unnamed: C7.2, U1.9 (XTAL1/PB6), Y1.2
unnamed: C8.2, U1.10 (XTAL2/PB7), Y1.1
unnamed: C9.1, U4.1 (OSCI), Y2.1
unnamed: C12.1, R3.1
unnamed: C13.1, J3.1
unnamed: C14.1, D2.1 (K), D4.3 (K), R3.2, U4.8 (VDD)
unnamed: D1.2 (A), R1.1
unnamed: D3.2 (A), R8.1
unnamed: J1.2, R7.2
unnamed: JP1.2, U6.2 (VCC)
unnamed: R8.2, U1.26 (PC3)
unnamed: U4.2 (OSCO), Y2.2
PB0: J4.3, U1.14 (PB0)
PD5: J4.1, U1.11 (PD5)
PD6: J4.2, U1.12 (PD6)
RST: C13.2, R2.2, U1.1 (~RESET~/PC6), U6.5 (RST)
RXD: J3.2, U1.2 (PD0)
SCK: U1.19 (PB5), U3.5 (SCK), U6.7 (SCK)
SCL: R5.1, U1.28 (PC5), U4.6 (SCL)
SDA: R4.1, U1.27 (PC4), U4.5 (SDA)
SS: U1.16 (PB2), U3.4 (CS)
TXD: J3.3, U1.3 (PD1)
WS2811_PIN: R7.1, U1.13 (PD7)

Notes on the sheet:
AVR-ISP AND UART
POWER
RTC PCF8563
NRF24l04
ATMEGA 328
SOLDER THT OR SMD Version
Use Only one of U2,U7,U8

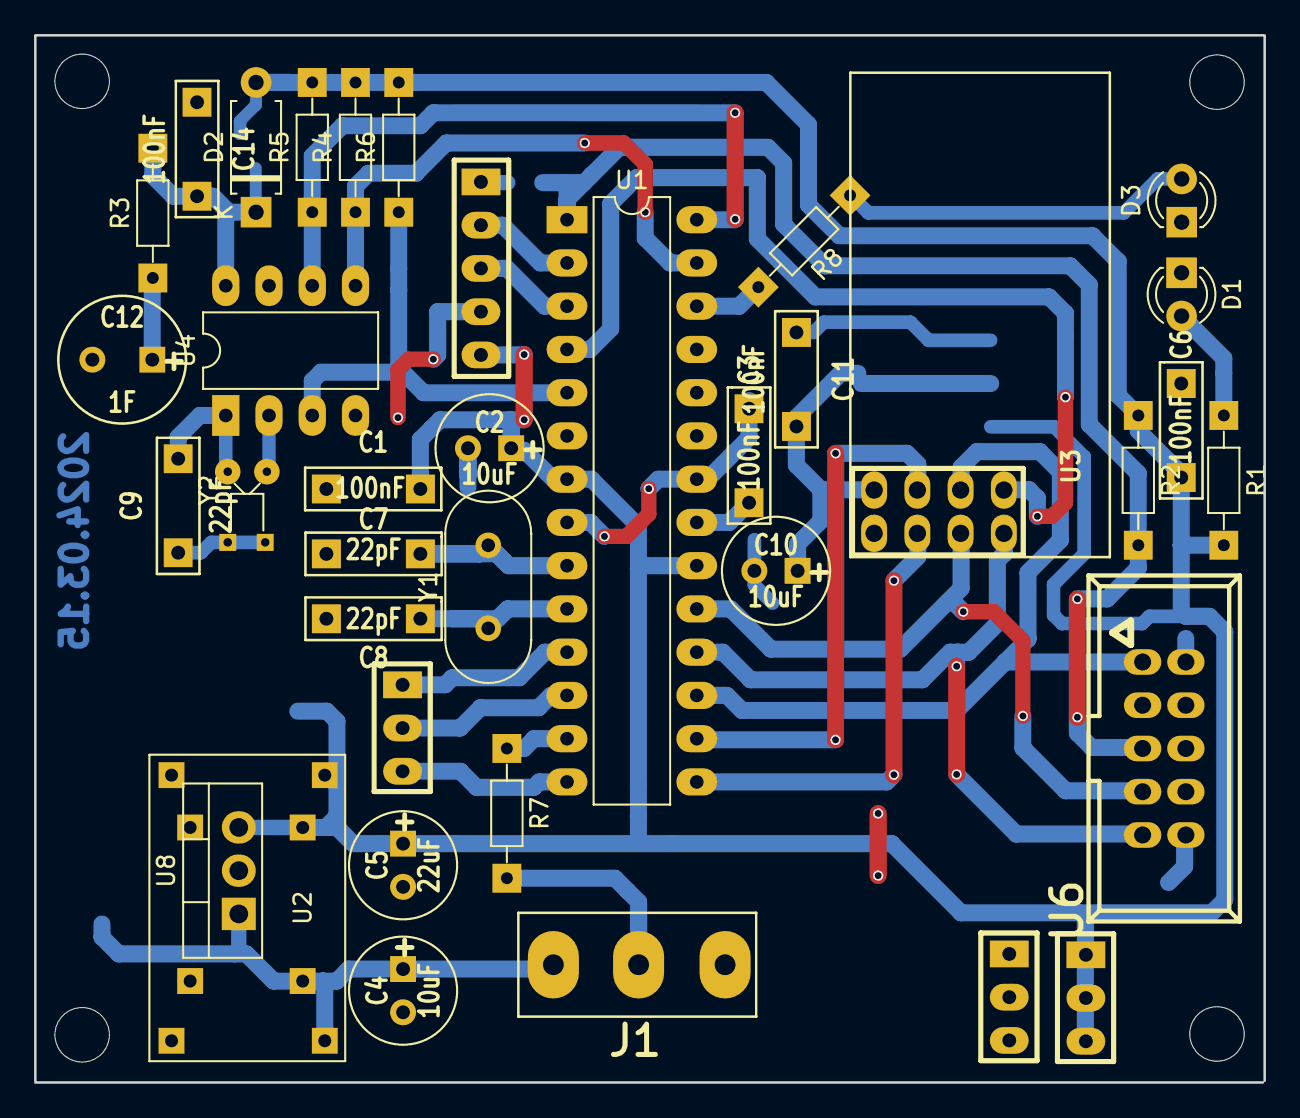
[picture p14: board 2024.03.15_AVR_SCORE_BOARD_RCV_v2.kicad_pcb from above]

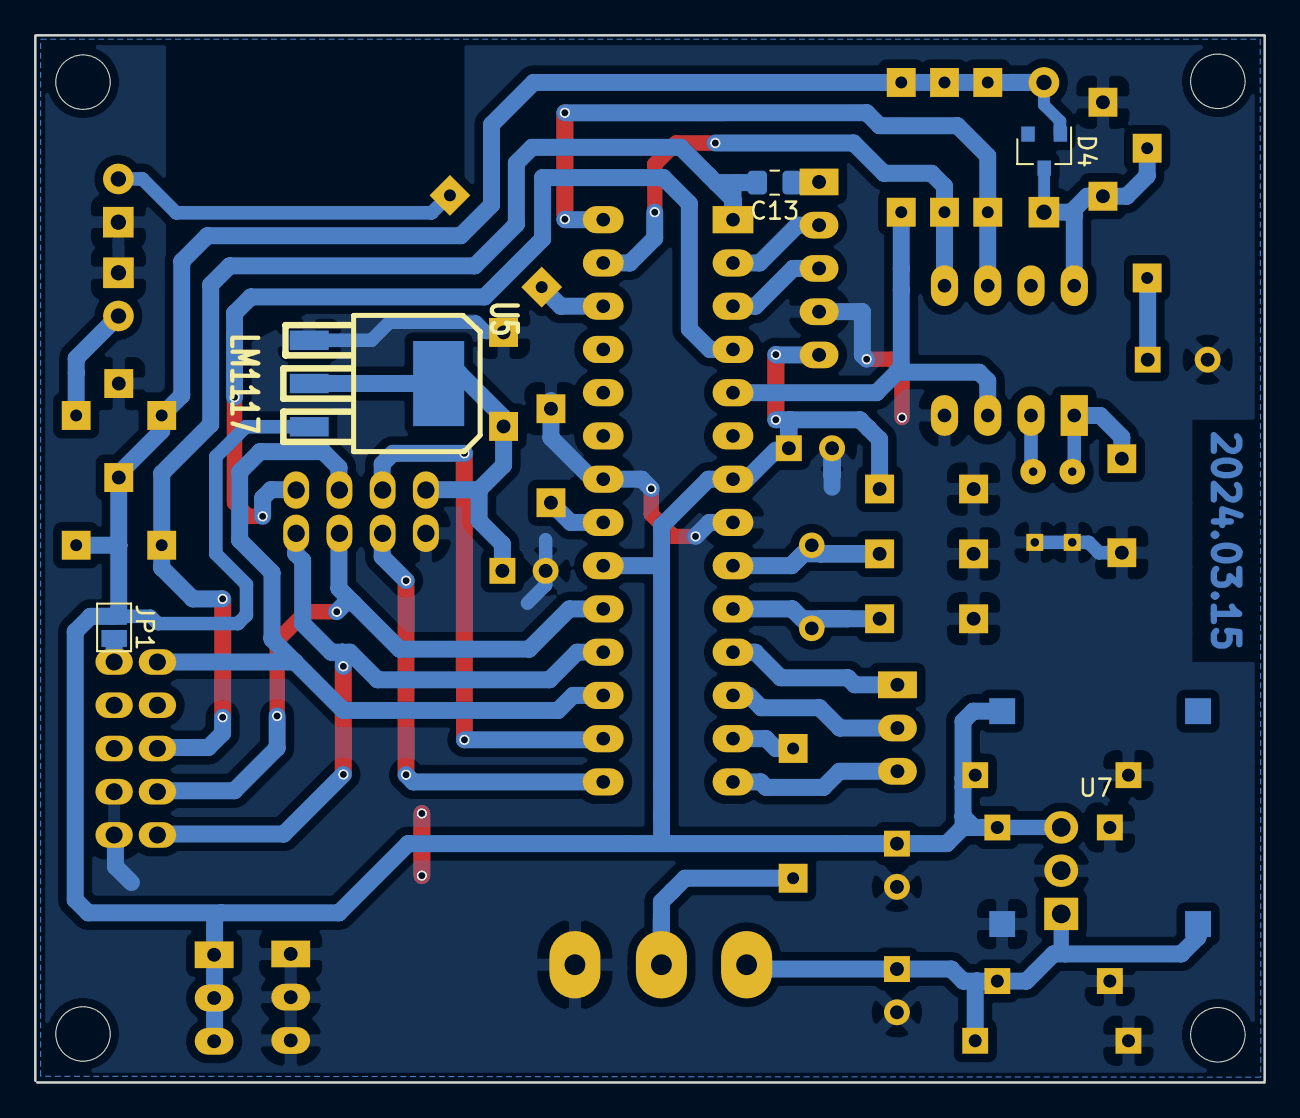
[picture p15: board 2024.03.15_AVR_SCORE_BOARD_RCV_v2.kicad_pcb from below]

Board: 2 copper layers, 72.2 x 61.5 mm, 46 parts (5 on the bottom side), 33 nets.

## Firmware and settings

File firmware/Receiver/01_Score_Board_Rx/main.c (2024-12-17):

/*
 * main.c
 *
 *  Created on: Mar 17, 2018
 *      Author: user
 */

#include <stdio.h>
#include <stdlib.h>
#include <string.h>
#include <avr/io.h>
#include <avr/interrupt.h>

#include <avr/pgmspace.h>
#include <util/delay.h>

#include "nrf24l01/nrf24l01.h"


#include "Light_WS2812/light_ws2812.h"
#include "Light_WS2812/led_led.h"


#include "I2C_TWI/pcf8563p.h"
#include "I2C_TWI/i2c.h"

#include "UART/uart.h"


volatile uint8_t int1_flag = 0;


void disp_time(void){

	rtc_refresh_date();

	dwukropek =! dwukropek;

	update_LED();
}




int main(void) {

	_delay_ms(1000);//wait to init pcf8563

	DDRC |= (1<<PC3);//

//	PORTC |= (1<<PC4) | (1<<PC5);//pullup on SDA and SCL - for arduino

	DDRD |= (1<<ws2812_pin);

	char bufferin[NRF24L01_PAYLOAD];


	//enable RTC interrupt (INT1)
	EICRA |= (1 << ISC11);
	EIMSK |= (1 << INT1);
//	PORTD |= (1 << PD3); //not needed if hardware pullup resistor is placed

	uart_init(UBRR);
	uart_puts("Score Board v2.0\r\n");

	nrf24l01_init();

	sei();

	i2cSetBitrate(100);

	rtc_init();

	off_timer = SECONDS_TO_SUSPEND;

	update_LED();

	while (1) {


		if(int1_flag){


			PORTC ^= (1<<PC3);


			if(play_time_on == 1){
				play_time_ss++;
				if(play_time_ss == 60){
					play_time_mm++;
					play_time_ss = 0;
				}
				if(play_time_mm == 60) play_time_mm = 0;
			}


			if(off_timer != 0){
				off_timer--; //decrementing time to disable leds
			}
			disp_time();

			uart_putlong(pcf8563_rtc.hours, 10);
			uart_putc(':');
			uart_putlong(pcf8563_rtc.minutes, 10);
			uart_putc(':');
			uart_putlong(pcf8563_rtc.seconds, 10);
			
			
			uart_puts(" off_timer: ");
			uart_putlong(off_timer, 10);
			uart_putc('\r');
			uart_putc('\n');
			

			int1_flag = 0;
		}


		uint8_t pipe = 0;
		if (nrf24l01_readready(&pipe)) { //if data is ready
			off_timer = SECONDS_TO_SUSPEND;


			//read buffer
			nrf24l01_read((uint8_t*)bufferin);

			if(!strcmp(bufferin, "D1S+")){//setyA++
				set_A++;
			}
			else if(!strcmp(bufferin, "D1S-")){//setyA--
				set_A--;
			}
			else if(!strcmp(bufferin, "D1P+")){//punktyA++
				punkty_A++;
			}
			else if(!strcmp(bufferin, "D1P-")){//punktyA--
				punkty_A--;
			}
			else if(!strcmp(bufferin, "D2S+")){//setyB++
				set_B++;
			}
			else if(!strcmp(bufferin, "D2S-")){//setyB--
				set_B--;
			}
			else if(!strcmp(bufferin, "D2P+")){//punktyB++
				punkty_B++;
			}
			else if(!strcmp(bufferin, "D2P-")){//punktyB--
				punkty_B--;
			}
			else if(!strcmp(bufferin, "RSTS")){//sety rst
				set_A=0;
				set_B=0;
			}
			else if(!strcmp(bufferin, "RSTP")){//punkty rst
				punkty_A=0;
				punkty_B=0;
			}
			else if(!strcmp(bufferin, "TPPS")){//play time on off
				play_time_on ^= 1;
			}
			else if(!strcmp(bufferin, "TRST")){//play time rst
				play_time_mm = 0;
				play_time_ss = 0;
			}
			else if(!strcmp(bufferin, "HOR+")){//hours
				pcf8563_rtc.hours++;
				if(pcf8563_rtc.hours >= 24)pcf8563_rtc.hours = 0;
				rtc_write_date();
				disp_time();

			}
			else if(!strcmp(bufferin, "MIN+")){//minutes
				pcf8563_rtc.minutes++;
				if(pcf8563_rtc.minutes >= 60)pcf8563_rtc.minutes = 0;
				rtc_write_date();
				disp_time();
			}

			uart_puts("rx cmd: ");
			uart_puts(bufferin);
			uart_putc('\r');
			uart_putc('\n');

			update_LED();


		}


	}//end WHILE
}//end MAIN



ISR( INT1_vect ) {
	int1_flag = 1;
}

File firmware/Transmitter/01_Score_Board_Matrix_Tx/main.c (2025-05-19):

/*
 * main.c
 *
 *  Created on: Sep 10, 2018
 *      Author: user
 */


#include <avr/io.h>
#include <avr/interrupt.h>
#include <avr/sleep.h>
#include <util/delay.h>

#include <stdio.h>
#include <stdlib.h>
#include <string.h>
#include <avr/wdt.h>

#include "UART/uart.h"
#include "nrf24l01/nrf24l01.h"
#include "nrf24l01/nrf24l01registers.h"
#include "ADC/ADC.h"
#include "common.h"


uint8_t key_pressed;


uint8_t check_rows(uint8_t column){
	uint8_t to_return = 0;

	if(!(PINC & ROW1_PIN)){
		to_return = (column * 4 + 1);
	}
	if(!(PINC & ROW2_PIN)){
		to_return = (column * 4 + 2);
	}
	if(!(PINC & ROW3_PIN)){
		to_return = (column * 4 + 3);
	}
	if(!(PINC & ROW4_PIN)){
		to_return = (column * 4 + 4);
	}
	if(!(PINC & ROW1_PIN) && !(PINC & ROW2_PIN)){
		to_return = (column * 4 + 35);
	}
	if(!(PINC & ROW3_PIN) && !(PINC & ROW4_PIN)){
		to_return = (column * 4 + 36);
	}

	return to_return;
}


uint8_t scan_keys(void)
{
	uint8_t key = 0;


	uint8_t rows_tmp = 0;

	COL_PORT &= ~COL1_PIN;//COL1 LOW
	rows_tmp = check_rows(0);
	if(rows_tmp){
		key = rows_tmp;
	}
	COL_PORT |= COL1_PIN;//COL1 HIGH


	COL_PORT &= ~COL2_PIN;//COL2 LOW
	rows_tmp = check_rows(1);
	if(rows_tmp){
		key = rows_tmp;
	}
	COL_PORT |= COL2_PIN;//COL2 HIGH


	COL_PORT &= ~COL3_PIN;//COL3 LOW
	rows_tmp = check_rows(2);
	if(rows_tmp){
		key = rows_tmp;
	}
	COL_PORT |= COL3_PIN;//COL3 HIGH


	return key;
}


volatile uint8_t int_flag = 0;
int main(void) {


#ifdef DBG
	uart_init(UBRR);//UART baud 9600
#endif

	nrf24l01_init();
	InitADC();
	_delay_ms(100);

	LED_R_LOW_BATT_PIN_SET_AS_OUT;
	LED_R_LOW_BATT_OFF;//low battery LED off

	LED_G_TX_PIN_SET_AS_OUT;
	LED_G_TX_OFF;//tx LED off

	ROW_DDR &= ~ROW1_PIN | ROW2_PIN | ROW3_PIN | ROW4_PIN;//Rows Input
	ROW_PORT |= ROW1_PIN | ROW2_PIN | ROW3_PIN | ROW4_PIN;//Rows Input Pullup

	COL_DDR |= COL1_PIN | COL2_PIN | COL3_PIN;//Col Output
	COL_PORT &= ~(COL1_PIN | COL2_PIN | COL3_PIN);//Col Output LOW

	//Enable PCINT INTERRUPT
	PCICR |= (1<<PCIE1);
	PCMSK1 |= (1<<PCINT9)|(1<<PCINT10)|(1<<PCINT11)|(1<<PCINT12);

	//disable nrf
	nrf24l01_CElo;

	sei();


	while (1) {
		if(int_flag == 1){
			nrf24l01_CEhi;
			_delay_ms(10);

			uint32_t adc_value_average = 0;

			uint16_t adc_value = get_adc_value(0);

			for(uint8_t i = 0 ; i <= 20 ; i++){
				adc_value_average += adc_value;
			}
			adc_value_average = adc_value_average/20;

#ifdef DBG
			uart_putlong(adc_value_average, 10);
			uart_puts("\r\n");
#endif


			if (adc_value_average < 470){//lower than 2,55V
				LED_R_LOW_BATT_ON;//low battery LED on
//				BUZZ_ON;
				_delay_ms(K_DELAY_TIME);
			}else{
				LED_G_TX_ON;//tx LED on
				key_pressed = scan_keys();
				CheckKeys(key_pressed);
			}

			LED_R_LOW_BATT_OFF;//low battery LED off
			LED_G_TX_OFF;//tx LED off
//			BUZZ_OFF;


			COL_PORT &= ~(COL1_PIN | COL2_PIN | COL3_PIN);//Col Output LOW
			nrf24l01_CElo;


			int_flag = 0;
		}else{

			go_to_sleep();

		}


	}
}



ISR(PCINT1_vect)
{
	int_flag = 1;
}

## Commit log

2024-03-10 RX Board Firmware
2024-03-12 LEDs Wiring
2024-03-15 Hardware v2
    [2024.03.15_AVR_SCORE_BOARD_RCV_v2.kicad_pcb, 2024.03.15_AVR_SCORE_BOARD_RCV_v2.sch]
2024-03-23 change design to 5v logic level
    [2024.03.15_AVR_SCORE_BOARD_RCV_v2.kicad_pcb, 2024.03.15_AVR_SCORE_BOARD_RCV_v2.sch]
2024-03-23 changed wrong footprints
    [2024.03.15_AVR_SCORE_BOARD_RCV_v2.kicad_pcb, 2024.03.15_AVR_SCORE_BOARD_RCV_v2.sch]
2024-04-04 Added 100nF capacitor for rtc
    [2024.03.15_AVR_SCORE_BOARD_RCV_v2.kicad_pcb, 2024.03.15_AVR_SCORE_BOARD_RCV_v2.sch]
2024-04-19 Added v2 version of TX schematic and pcb
    [2024.03.15_AVR_SCORE_BOARD_RCV_v2.kicad_pcb, 2024.03.15_AVR_SCORE_BOARD_TX_v2.kicad_pcb, 2024.03.15_AVR_SCORE_BOARD_TX_v2.sch]
2024-04-20 Added LP2980 voltage regulator for NRF24L01
    [2024.03.15_AVR_SCORE_BOARD_TX_v2.kicad_pcb, 2024.03.15_AVR_SCORE_BOARD_TX_v2.sch]
2024-04-20 Fixed NRF24L01 schematic symbol
    [2024.03.15_AVR_SCORE_BOARD_RCV_v2.kicad_pcb, 2024.03.15_AVR_SCORE_BOARD_RCV_v2.sch]
2024-06-06 RCV Hardware updated - Voltage regulation
    [2024.03.15_AVR_SCORE_BOARD_RCV_v2.kicad_pcb, 2024.03.15_AVR_SCORE_BOARD_RCV_v2.sch, 2024.03.15_AVR_SCORE_BOARD_TX_v2.kicad_pcb]
2024-10-24 Added USB_B for charging and moved old schematic
    [2024.03.15_AVR_SCORE_BOARD_TX_v2.kicad_pcb, 2024.03.15_AVR_SCORE_BOARD_TX_v2.sch]
2024-10-24 Add RCV schematic in PDF
2024-12-17 UART debug messages
2025-01-13 Added ADC check
2025-03-06 Ground fill fixed
    [2024.03.15_AVR_SCORE_BOARD_TX_v2.kicad_pcb]
2025-04-07 ADC Average
2025-05-19 Update label
    [2024.03.15_AVR_SCORE_BOARD_TX_v2.kicad_pcb, 2024.03.15_AVR_SCORE_BOARD_TX_v2.sch]
